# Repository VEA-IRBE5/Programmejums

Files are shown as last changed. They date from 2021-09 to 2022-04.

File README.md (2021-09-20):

# Programmējums
Zondes borta datora (mikrokontroliera) programmējums

# Programmēšanas stila vadlīnijas
Šīs ir tikai vadlīnijas, nesitīšu ja perfekti nesekosiet tām. Galvenais, lai kods ir saprotams un pārskatāms
- Tabulācija ir 4 atstarpes
- Komentārus var latviski/english, galvenais lai ir saprotami un labi apraksta kodu
- Iesaku komentārus netaupīt, tiklīdz kaut kas liekas ne pilnīgi pašsaprotams, raksti komentāru
- Komentāru garumam nevajadzētu pārsniegt 2 - 3 līnijas

## Mainīgo noformējums
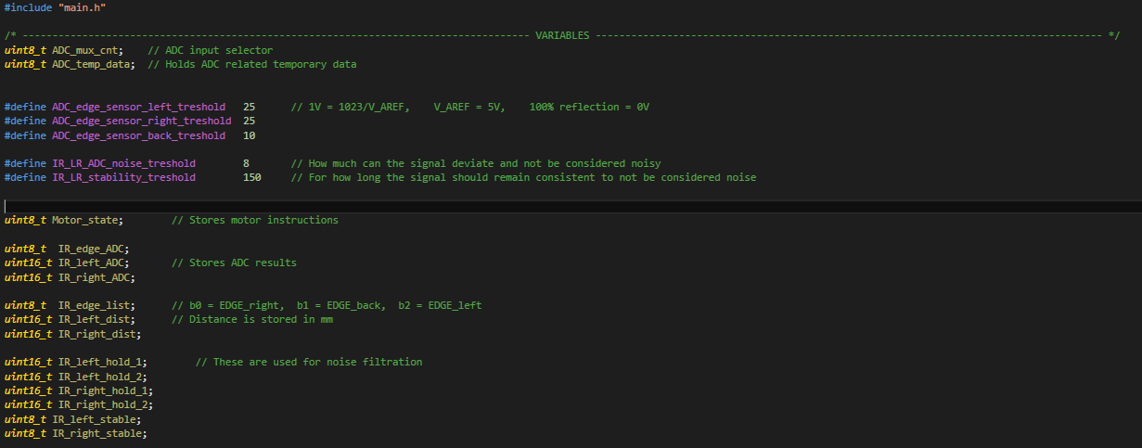
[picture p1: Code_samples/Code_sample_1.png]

- Mainīgo nosaukums var būt īsi līdz vidēji tekstuāls, galvenais lai no nosaukuma ir aptuveni skaidrs, kur izmanto
- Visim mainīgiem ir jābūt definētiem vienā vietā (vai divās) un, kur nepieiciešams, ar komentāriem aprakstīts to pielietojums
- Šīs pašas vadlīnijas arī attiecas uz definētām konstantēm
- Lūgums turēt mainīgos ārpus header (main.h) faila, cik iespējams (Uz konstantēm tas neattiecas)

## Koda noformējums
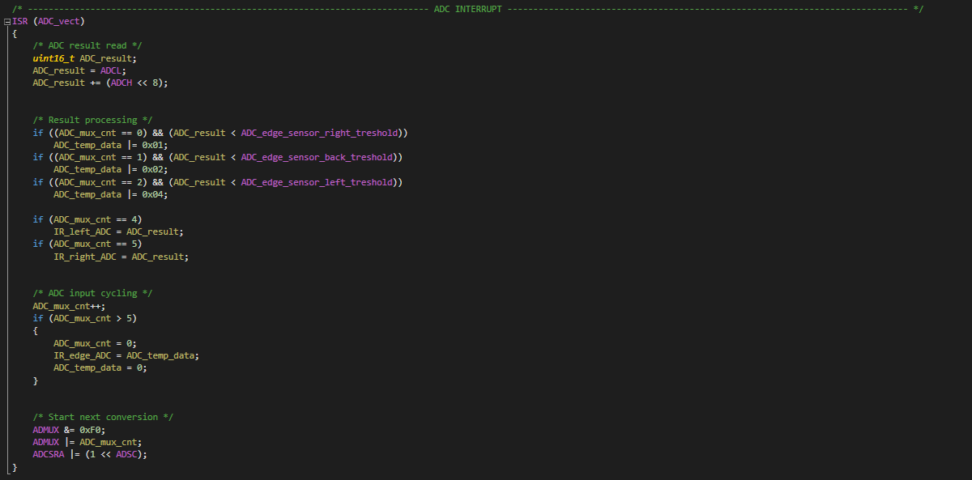
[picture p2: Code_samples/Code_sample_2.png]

- Galvenā doma ir sadalīšana pa blokiem ar attiecīgām komentētām sadalēm
- Piemērā ir redzams ADC pārtraukums kā galvenais bloks, ar iekšējiem darbības soļiem sadalītiem mazākos blokos
- Var dalīt kodu pa blokiem arī pēc saviem ieskatiem, galvenais lai ir labi sadalīts

## #include un funkcijas
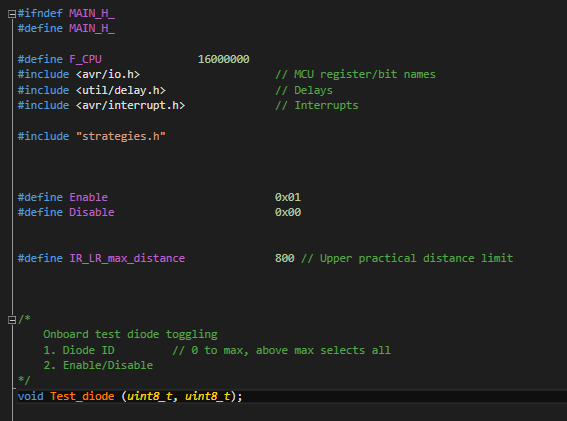
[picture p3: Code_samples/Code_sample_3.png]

- Pie #include droši rakstiet komentārus
- Funkcijām lūdzu veidot aprakstu, pasakot ko dara, ko ievada (ar mainīgo aprakstu) un ko izvada
- Ja izmantojat gatavus koda blokus no citiem avotiem, tos iesaku turēt atsevišķos failos un integrēt kā funkcijas

# Git bash konfigurācija un lokālās repozitorijas izveide

### 1. Instalē git bash

### 2. Izveido mapi, kurā glabās projektu

### 3. R-click(otrais peles taustiņš) -> Git bash here
  - Ja nerāda, atver git bash un ar cd navigē uz izveidoto mapi

### 4. Konsolē: git config --global user.name "Vards Uzvards" 
- git config --global user.email "epasts@mail.com"
  - Izmanto to epastu, kurš piesaistīts profilam, kas var tikt klāt IRBE5 repozitorijai
  - Var pārbaudīt, vai pareizi saglabāts ar tām pašām komandām, noņemot "" specificētos datus

### 5. (Neobligāts)Konsolē: git config --global core.editor "'C:/Program Files/Notepad++/notepad++.exe' -multiInst -notabbar -nosession -noPlugin"
  - var uzstādīt notepad++ kā default teksta editoru, kad raksta commit komentāru
  - Iesaku izdarīt, jo konsoles teksta editors nav ērts

### 6. Konsolē: git config --global init.defaultBranch main
- Citādi defaults būs master, un tas var radīt problēmas

### 7. Konsolē: git config --list
- Ar šo var pārbaudīt git bash konfigurāciju

### 8. Beidzot inicializē lokālo repozitoriju: git init

# Darbība ar lokālo github repositoriju

### 1. Konsolē: git remote add IRBE5 https://github.com/VEA-IRBE5/Programmejums.git
- turpmāk pie git pull var izmantot IRBE5 nevis pilno linku 
- ar šo pastās, vai sarakstā ir Konsolē: git remote -v

### 2. Konsolē: git pull IRBE5 [Branch name]
- Lejupielādē norādītā zara saturu no repozitorijas, par zaru lietošanu konsultējies ar nodaļas galveno

### 3. Pēc pašreizējās darba tūres beigšanas neaizmirsti izveidot commit, lai dati nepazūd
- Konsolē: git add . (vai git add "filename", ja negrib visas izmaiņas pievienot)
- Konsolē: git status (pastās, vai viss ir ok)
- Konsolē: git commit (Lūdzu izsmeļoši un ne pārāk gari aprakstiet izmainīto)(var izmantot: -m "Text here")
   
### 4. Kad liekas, ka pašreizējais uzdevums ir gana labā stāvoklī, Konsolē: git push IRBE5 [Branch name]

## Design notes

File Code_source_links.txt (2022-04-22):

http://www.emcu.eu/how-to-manage-two-uart-usart2-and-usart1-under-interrupt/
https://github.com/Xxxxhx/STM32_HAL_Tutorial/blob/master/4-Timer%20Interrupt.md
https://the78mole.de/stm32-uart-continuous-receive-with-interrupt/
https://controllerstech.com/sd-card-using-spi-in-stm32/
https://cdn-shop.adafruit.com/datasheets/Si1145-46-47.pdf

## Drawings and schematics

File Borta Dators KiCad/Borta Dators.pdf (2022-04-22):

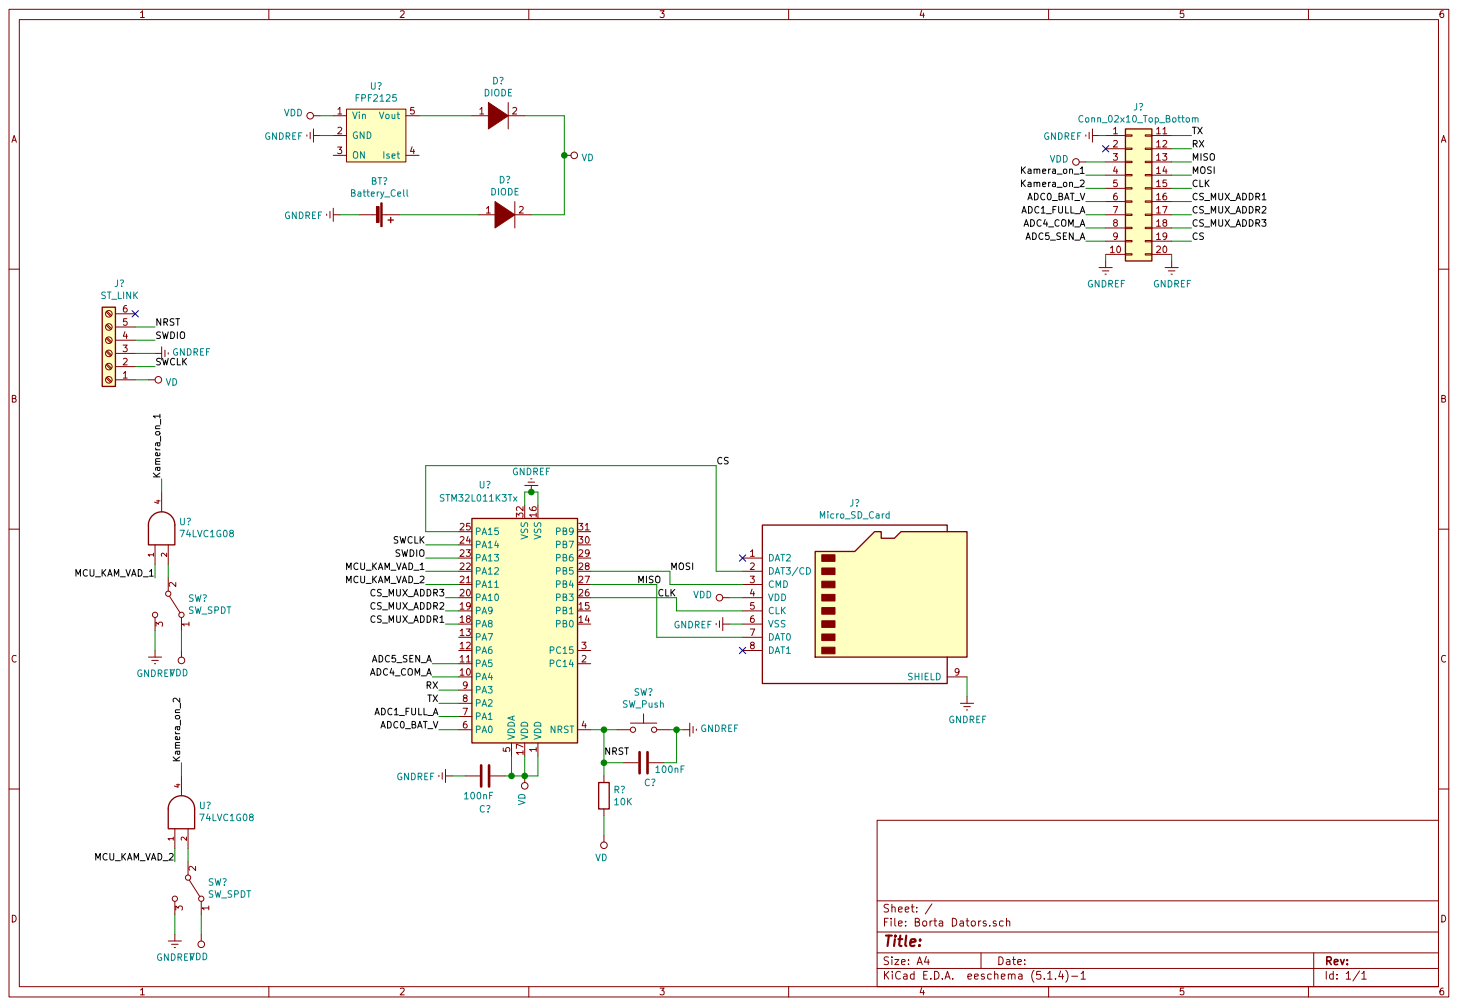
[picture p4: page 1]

Id: 1/1 Title: File: Borta Dators.sch Sheet: /

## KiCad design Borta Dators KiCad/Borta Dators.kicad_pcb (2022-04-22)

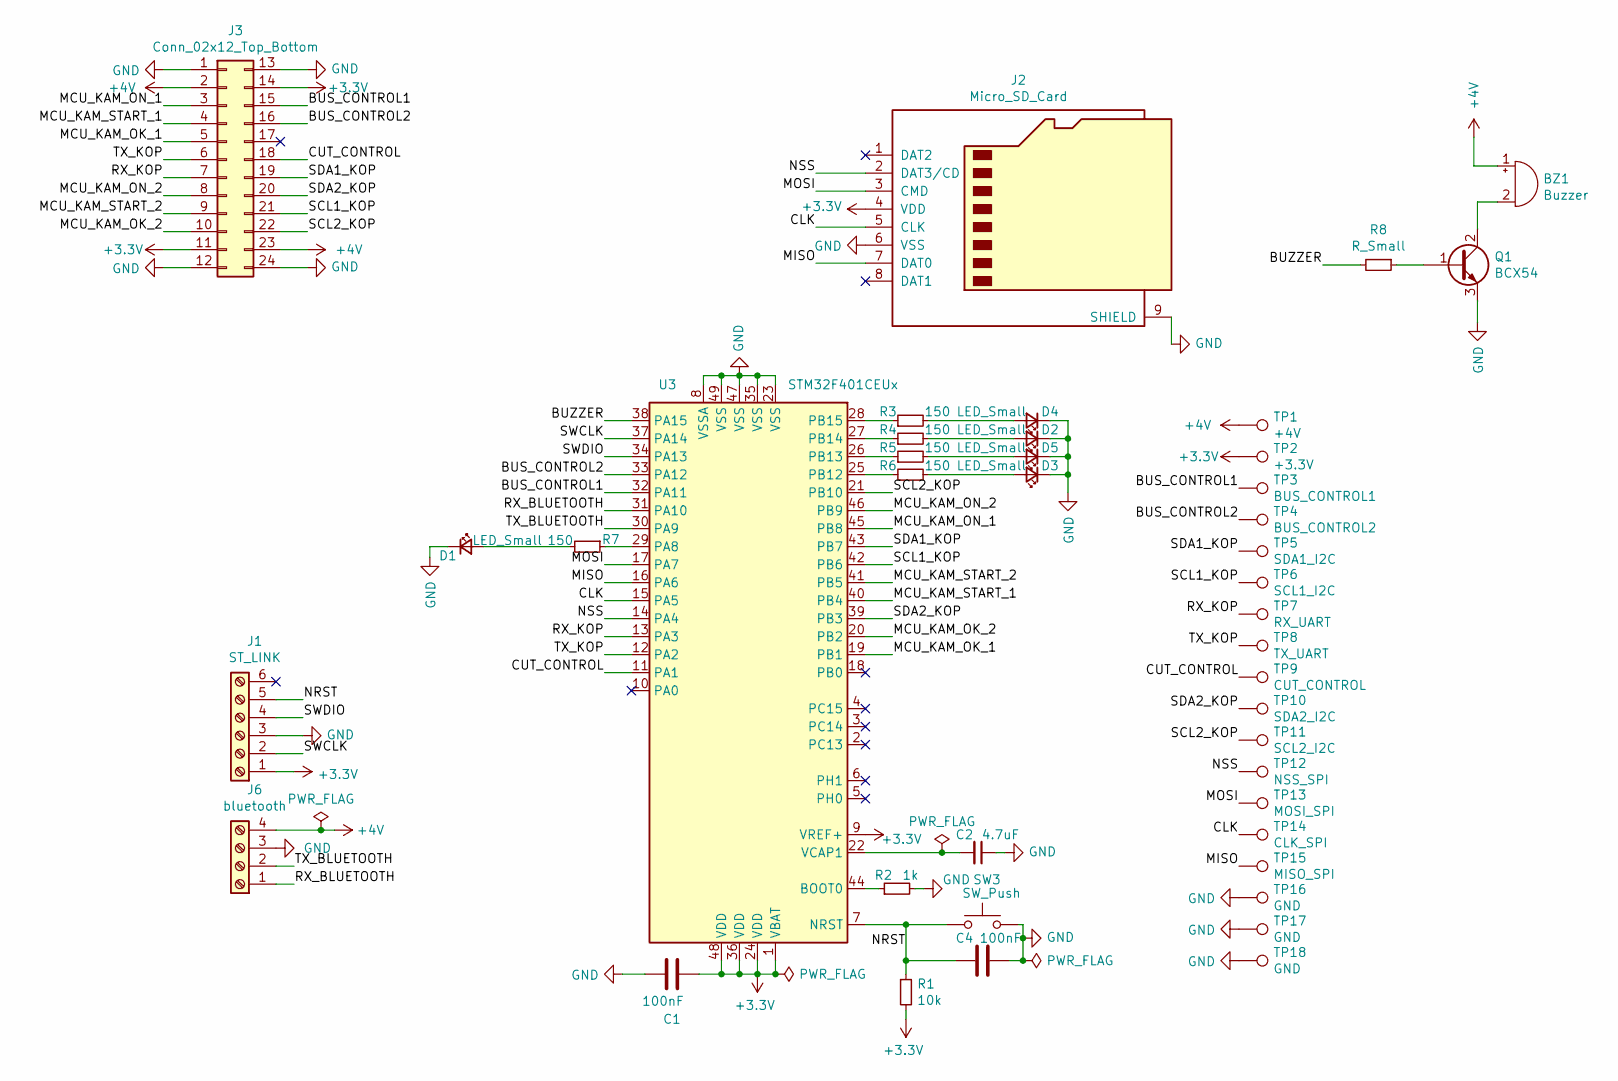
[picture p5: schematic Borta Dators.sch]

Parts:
BZ1: Buzzer; PinHeader_1x02_P1.27mm_Vertical
C1, C4: 100nF; C_0603_1608Metric_Pad1.08x0.95mm_HandSolder
C2: 4.7uF; C_0603_1608Metric_Pad1.08x0.95mm_HandSolder
D1, D2, D3, D4, D5: LED_Small; D_0603_1608Metric_Pad1.05x0.95mm_HandSolder
J1: ST_LINK; PinSocket_1x06_P2.54mm_Vertical
J2: Micro_SD_Card; Micro_SD
J3: Conn_02x12_Top_Bottom; SAMTEC-SSW-112-02-X-D-RA
J6: bluetooth; PinSocket_1x04_P2.54mm_Vertical
Q1: BCX54; SOT-89-3
R1: 10k; R_0603_1608Metric_Pad0.98x0.95mm_HandSolder
R2: 1k; R_0603_1608Metric_Pad0.98x0.95mm_HandSolder
R3, R4, R5, R6, R7: 150; R_0603_1608Metric_Pad0.98x0.95mm_HandSolder
R8: R_Small; R_0603_1608Metric_Pad0.98x0.95mm_HandSolder
SW3: SW_Push; SW_SPST_EVQQ2
TP1: +4V; PinHeader_1x01_P2.54mm_Vertical
TP2: +3.3V; PinHeader_1x01_P2.54mm_Vertical
TP3: BUS_CONTROL1; PinHeader_1x01_P2.54mm_Vertical
TP4: BUS_CONTROL2; PinHeader_1x01_P2.54mm_Vertical
TP5: SDA1_I2C; PinHeader_1x01_P2.54mm_Vertical
TP6: SCL1_I2C; PinHeader_1x01_P2.54mm_Vertical
TP7: RX_UART; PinHeader_1x01_P2.54mm_Vertical
TP8: TX_UART; PinHeader_1x01_P2.54mm_Vertical
TP9: CUT_CONTROL; PinHeader_1x01_P2.54mm_Vertical
TP10: SDA2_I2C; PinHeader_1x01_P2.54mm_Vertical
TP11: SCL2_I2C; PinHeader_1x01_P2.54mm_Vertical
TP12: NSS_SPI; PinHeader_1x01_P2.54mm_Vertical
TP13: MOSI_SPI; PinHeader_1x01_P2.54mm_Vertical
TP14: CLK_SPI; PinHeader_1x01_P2.54mm_Vertical
TP15: MISO_SPI; PinHeader_1x01_P2.54mm_Vertical
TP16, TP17, TP18: GND; PinHeader_1x01_P2.54mm_Vertical
U3: STM32F401CEUx; QFN-48-1EP_7x7mm_P0.5mm_EP5.6x5.6mm

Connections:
+3V3: C1.1, J1.1, J2.4 (VDD), J3.11, J3.14, R1.2, TP2.1, U3.1 (VBAT), U3.9 (VREF+), U3.24 (VDD), U3.36 (VDD), U3.48 (VDD); also elsewhere on the board
+4V: BZ1.1 (-), J3.2, J3.23, J6.4, TP1.1
/BUS_CONTROL1: J3.15, TP3.1, U3.32 (PA11); also elsewhere on the board
/BUS_CONTROL2: J3.16, TP4.1, U3.33 (PA12); also elsewhere on the board
/BUZZER: R8.2, U3.38 (PA15); also elsewhere on the board
/CLK: J2.5 (CLK), TP14.1, U3.15 (PA5); also elsewhere on the board
/CUT_CONTROL: J3.18, TP9.1, U3.11 (PA1); also elsewhere on the board
/MCU_KAM_OK_1: J3.5, U3.19 (PB1); also elsewhere on the board
/MCU_KAM_OK_2: J3.10, U3.20 (PB2); also elsewhere on the board
/MCU_KAM_ON_1: J3.3, U3.45 (PB8); also elsewhere on the board
/MCU_KAM_ON_2: J3.8, U3.46 (PB9); also elsewhere on the board
/MCU_KAM_START_1: J3.4, U3.40 (PB4); also elsewhere on the board
/MCU_KAM_START_2: J3.9, U3.41 (PB5); also elsewhere on the board
/MISO: J2.7 (DAT0), TP15.1, U3.16 (PA6); also elsewhere on the board
/MOSI: J2.3 (CMD), TP13.1, U3.17 (PA7); also elsewhere on the board
/NRST: C4.1, J1.5, R1.1, SW3.1, U3.7 (NRST); also elsewhere on the board
/NSS: J2.2 (DAT3/CD), TP12.1, U3.14 (PA4); also elsewhere on the board
/RX_BLUETOOTH: J6.1, U3.31 (PA10); also elsewhere on the board
/RX_KOP: J3.7, TP7.1, U3.13 (PA3); also elsewhere on the board
/SCL1_KOP: J3.21, TP6.1, U3.42 (PB6); also elsewhere on the board
/SCL2_KOP: J3.22, TP11.1, U3.21 (PB10); also elsewhere on the board
/SDA1_KOP: J3.19, TP5.1, U3.43 (PB7); also elsewhere on the board
/SDA2_KOP: J3.20, TP10.1, U3.39 (PB3); also elsewhere on the board
/SWCLK: J1.2, U3.37 (PA14); also elsewhere on the board
/SWDIO: J1.4, U3.34 (PA13); also elsewhere on the board
/TX_BLUETOOTH: J6.2, U3.30 (PA9); also elsewhere on the board
/TX_KOP: J3.6, TP8.1, U3.12 (PA2); also elsewhere on the board
GND: C1.2, C2.1, C4.2, D1.1 (K), D2.1 (K), D3.1 (K), D4.1 (K), D5.1 (K), J1.3, J2.6 (VSS), J2.9 (SHIELD), J3.1, J3.12, J3.13, J3.24, J6.3, Q1.3 (E), R2.2, SW3.2, TP16.1, TP17.1, TP18.1, U3.8 (VSSA), U3.23 (VSS), U3.35 (VSS), U3.47 (VSS), U3.49 (VSS); also elsewhere on the board
unnamed: BZ1.2 (+), Q1.2 (C)
unnamed 29: C2.2, U3.22 (VCAP1); also elsewhere on the board
unnamed: D1.2 (A), R7.2
unnamed: D2.2 (A), R4.2
unnamed: D3.2 (A), R6.2
unnamed: D4.2 (A), R3.2
unnamed: D5.2 (A), R5.2
unnamed: Q1.1 (B), R8.1
unnamed 40: R2.1, U3.44 (BOOT0); also elsewhere on the board
unnamed 41: R3.1, U3.28 (PB15); also elsewhere on the board
unnamed 42: R4.1, U3.27 (PB14); also elsewhere on the board
unnamed 43: R5.1, U3.26 (PB13); also elsewhere on the board
unnamed 44: R6.1, U3.25 (PB12); also elsewhere on the board
unnamed 45: R7.1, U3.29 (PA8); also elsewhere on the board

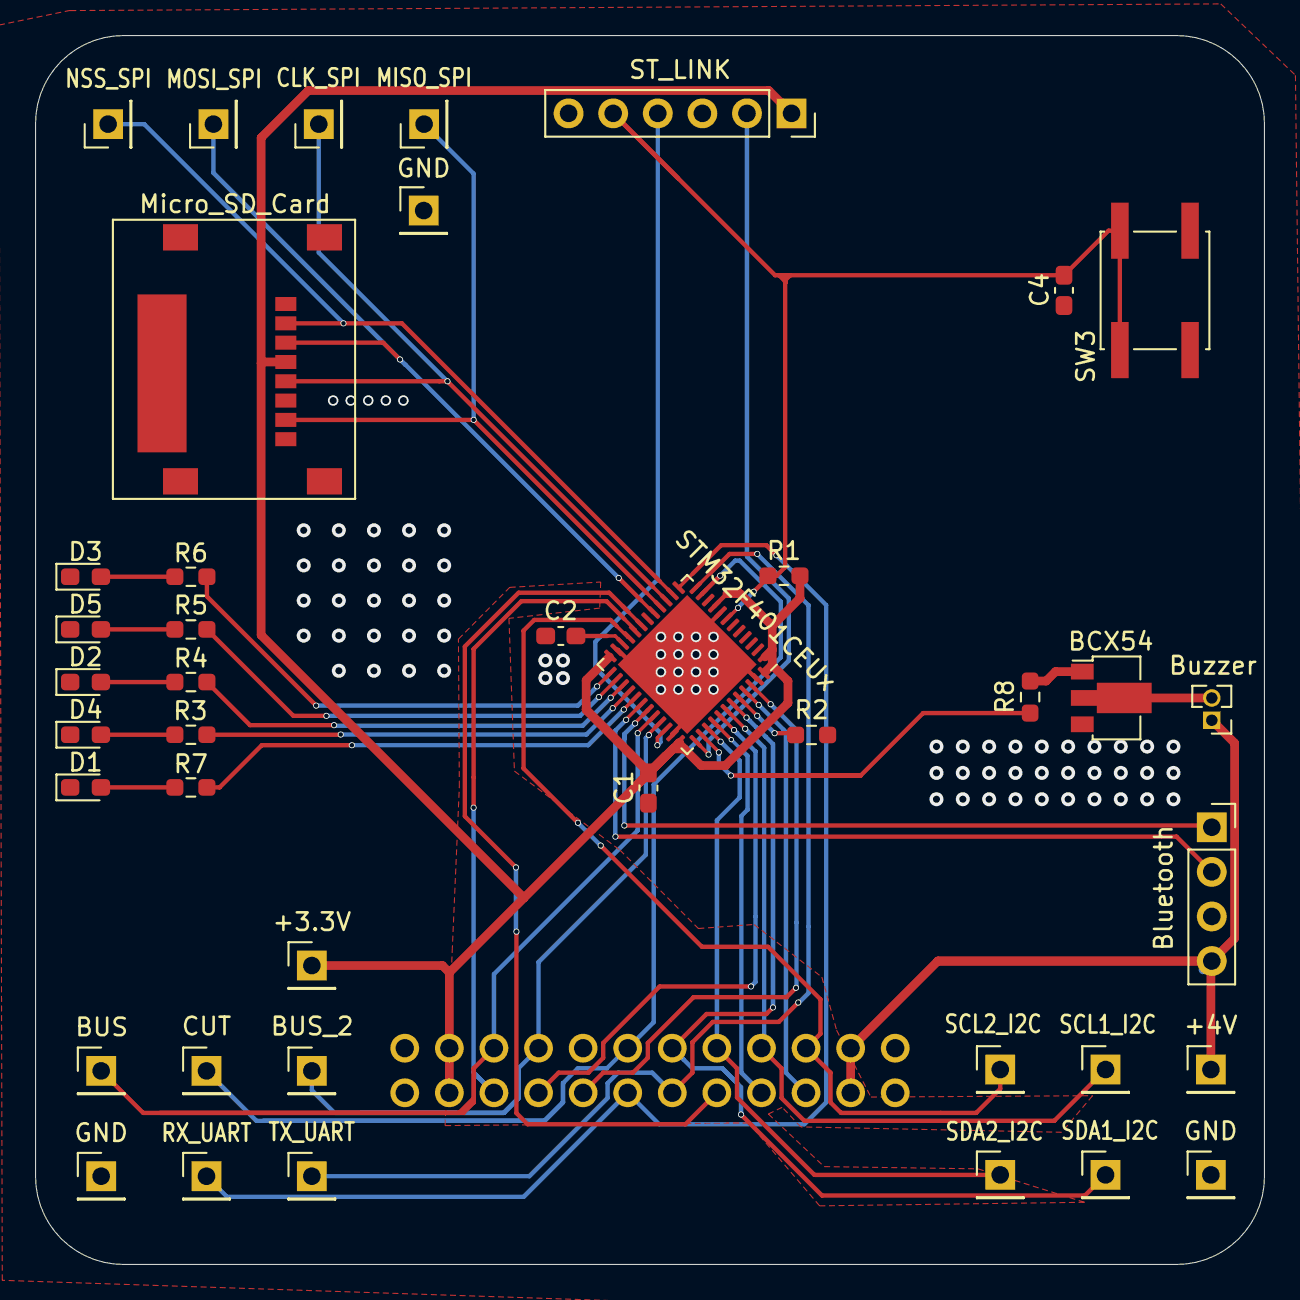
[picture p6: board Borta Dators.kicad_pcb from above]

Board: 2 copper layers, 70.0 x 70.0 mm, 42 parts (0 on the bottom side), 42 nets.

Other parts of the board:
TP109: BUS_2; PinHeader_1x01_P2.54mm_Vertical
Ue: STM32F401CEUx; QFN-48-1EP_7x7mm_P0.5mm_EP5.6x5.6mm

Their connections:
+3V3: Ue.1, Ue.9, Ue.24, Ue.36, Ue.48; also elsewhere on the board
/BUS_CONTROL1: Ue.32; also elsewhere on the board
/BUS_CONTROL2: TP109.1, Ue.33; also elsewhere on the board
/BUZZER: Ue.38; also elsewhere on the board
/CLK: Ue.15; also elsewhere on the board
/CUT_CONTROL: Ue.11; also elsewhere on the board
/MCU_KAM_OK_1: Ue.19; also elsewhere on the board
/MCU_KAM_OK_2: Ue.20; also elsewhere on the board
/MCU_KAM_ON_1: Ue.45; also elsewhere on the board
/MCU_KAM_ON_2: Ue.46; also elsewhere on the board
/MCU_KAM_START_1: Ue.40; also elsewhere on the board
/MCU_KAM_START_2: Ue.41; also elsewhere on the board
/MISO: Ue.16; also elsewhere on the board
/MOSI: Ue.17; also elsewhere on the board
/NRST: Ue.7; also elsewhere on the board
/NSS: Ue.14; also elsewhere on the board
/RX_BLUETOOTH: Ue.31; also elsewhere on the board
/RX_KOP: Ue.13; also elsewhere on the board
/SCL1_KOP: Ue.42; also elsewhere on the board
/SCL2_KOP: Ue.21; also elsewhere on the board
/SDA1_KOP: Ue.43; also elsewhere on the board
/SDA2_KOP: Ue.39; also elsewhere on the board
/SWCLK: Ue.37; also elsewhere on the board
/SWDIO: Ue.34; also elsewhere on the board
/TX_BLUETOOTH: Ue.30; also elsewhere on the board
/TX_KOP: Ue.12; also elsewhere on the board
GND: Ue.8, Ue.23, Ue.35, Ue.47, Ue.49; also elsewhere on the board
unnamed 29: Ue.22; also elsewhere on the board
unnamed 40: Ue.44; also elsewhere on the board
unnamed 41: Ue.28; also elsewhere on the board
unnamed 42: Ue.27; also elsewhere on the board
unnamed 43: Ue.26; also elsewhere on the board
unnamed 44: Ue.25; also elsewhere on the board
unnamed 45: Ue.29; also elsewhere on the board

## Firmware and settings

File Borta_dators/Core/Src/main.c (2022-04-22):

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
/* Includes ------------------------------------------------------------------*/
#include "main.h"
#include "fatfs.h"

/* USER CODE BEGIN Includes */
#include <math.h>
#include <stdio.h>
#include <string.h>
#include "BME280_lib.h"
#include "MPU6050_Lib.h"
#include "SI1145_lib.h"
/* USER CODE END Includes */

/* USER CODE BEGIN PD */

/* Buffer sizes */
#define UART_Buffer_size 50		// 2B command or nB data


/* Rope cut and sleep mode defines */
#define ROPE_NOT_CUT 0
#define ROPE_CUTTING 1
#define ROPE_CUT_DONE 2

#define ROPE_CUT_TIME 10			// in seconds
#define LOWER_ALTITUDE_LIMIT 1000 	// in meters
#define UPPER_ALTITUDE_LIMIT 28000 	// in meters
#define ALTITUDE_UPDATE_PERIOD 30	// in seconds


/* Sensor related defines */
#define I2C_BUS_SEL_BMEs 0
#define I2C_BUS_SEL_MPU__SI 1
#define I2C_handle_BME_ex__SI hi2c1
#define I2C_handle_BME_in__MPU hi2c2
#define I2C_short_timeout 20
#define I2C_long_timeout 200
#define PRESSURE_REFERENCE 100	//kpa at sea level, varies by location and weather


/* SD card related defines */
#define SD_MAX_RETRIES 5


/* Camera related defines */
#define CAM_NOK 0
#define CAM_OK 1
#define CAM_NREC 0
#define CAM_REC 1
#define CAM_STARTUP_TIME 6	// x*5 seconds

///* Timeout error defines */
//#define Timeout_none 0
//#define Timeout_SDcard 1
//#define Timeout_COM_uart 2
//#define Timeout_sensors 3

/* USER CODE END PD */

/* USER CODE BEGIN PM */
#define ARRAY_LENGTH(x) sizeof(x)/sizeof(x[0])

///* Timeout macros */
//#define Set_Timeout_Delay_ms(ms) __HAL_TIM_SET_AUTORELOAD(&htim2, ms)
//#define Start_Timeout __HAL_TIM_SET_COUNTER(&htim2, 0); HAL_TIM_Base_Start_IT(&htim2)
//#define Stop_Timeout HAL_TIM_Base_Stop_IT(&htim2)

/* USER CODE END PM */

I2C_HandleTypeDef hi2c1;
I2C_HandleTypeDef hi2c2;

RTC_HandleTypeDef hrtc;

SPI_HandleTypeDef hspi1;

TIM_HandleTypeDef htim3;
TIM_HandleTypeDef htim4;
TIM_HandleTypeDef htim5;
TIM_HandleTypeDef htim9;
TIM_HandleTypeDef htim10;

UART_HandleTypeDef huart1;
UART_HandleTypeDef huart2;

/* USER CODE BEGIN PV */

/* SD card handling variables */
FATFS fs;
FATFS *pfs;
FIL fil;
FRESULT fres;
DWORD fre_clust;
volatile uint32_t totalSpace, freeSpace;
char buffer[100];
volatile FRESULT sd_status;
volatile uint8_t sd_mounted;
volatile uint8_t sd_file_cnt;
volatile uint8_t sd_error_cnt;


/* System core and misc variables */
volatile uint8_t Is_asleep;
volatile uint8_t Rope_cut_delay, Rope_cut_status;
char message[] = "--test-please-ignore--";


/* Sensor data storage variables */
Sensors_struct Sensors;
char Data_to_send[UART_Buffer_size];

volatile uint16_t Cycle_runtime_last;
volatile uint16_t Cycle_runtime_min;
volatile uint16_t Cycle_runtime_max;

RTC_TimeTypeDef Current_Time;
RTC_DateTypeDef Current_Date;
volatile double Altitude_max;



/* UART1 specific */
uint8_t UART1_TxBuf[UART_Buffer_size];
uint8_t UART1_RxBuf[UART_Buffer_size];
uint8_t UART1_DataBuf[UART_Buffer_size];
volatile uint8_t UART1_RxIsData;
volatile uint8_t UART1_RxBytes;


/* UART2 specific */
uint8_t UART2_TxBuf[UART_Buffer_size];
uint8_t UART2_RxBuf[UART_Buffer_size];
uint8_t UART2_DataBuf[UART_Buffer_size];
volatile uint8_t UART2_RxIsData;
volatile uint8_t UART2_RxBytes;


/* CAM specific */
typedef struct CAM_struct
{
	GPIO_TypeDef *ON_PORT;
	uint16_t ON_PIN;
	GPIO_TypeDef *OK_PORT;
	uint16_t OK_PIN;
	GPIO_TypeDef *START_PORT;
	uint16_t START_PIN;
	TIM_HandleTypeDef *TIM;
	uint8_t REC_STATUS;
	uint8_t Do_Restart;
	uint8_t Do_EXTI;
	uint8_t Startup_delay;
} CAM_struct;

CAM_struct CAM_1;
CAM_struct CAM_2;

/* USER CODE END PV */

void SystemClock_Config(void);
static void MX_GPIO_Init(void);
static void MX_USART2_UART_Init(void);
static void MX_TIM4_Init(void);
static void MX_USART1_UART_Init(void);
static void MX_SPI1_Init(void);
static void MX_RTC_Init(void);
static void MX_TIM3_Init(void);
static void MX_I2C1_Init(void);
static void MX_I2C2_Init(void);
static void MX_TIM5_Init(void);
static void MX_TIM9_Init(void);
static void MX_TIM10_Init(void);
/* USER CODE BEGIN PFP */

void I2C_Select_bus(uint8_t select);
uint8_t Get_System_Status();
void Get_BME280_in_all_readings();
void Get_BME280_ex_all_readings();
void Get_MPU6050_all_readings();
void Get_SI1145_all_readings();
uint8_t Mount_open_SD_Card();

/* USER CODE END PFP */

/* USER CODE BEGIN 0 */


uint8_t Get_System_Status()
{
	uint8_t status = 0;

	if(Is_asleep == 1)
		status |= 1 << 8;
	if(Sensors.BME280_Internal.Status == HAL_OK)
		status |= 1 << 6;
	if(Sensors.BME280_External.Status == HAL_OK)
		status |= 1 << 5;
	if(Sensors.MPU650.Status == HAL_OK)
		status |= 1 << 4;
	if(Sensors.SI1145.Status == HAL_OK)
		status |= 1 << 3;
	if(sd_status == FR_OK)
		status |= 1 << 2;
	if(CAM_1.REC_STATUS == CAM_REC)
		status |= 1 << 1;
	if(CAM_2.REC_STATUS == CAM_REC)
		status |= 1;

	return status;
}
/*
 * Use defined I2C_BUS_SEL_ for input
 * anything not defined (above 1) deselects both
 */
void I2C_Select_bus(uint8_t select)
{
	switch(select)
	{
	case I2C_BUS_SEL_BMEs:
		HAL_GPIO_WritePin(BUS_SEL_1_GPIO_Port, BUS_SEL_1_Pin, GPIO_PIN_SET);
		HAL_GPIO_WritePin(BUS_SEL_2_GPIO_Port, BUS_SEL_2_Pin, GPIO_PIN_RESET);
		break;

	case I2C_BUS_SEL_MPU__SI:
		HAL_GPIO_WritePin(BUS_SEL_2_GPIO_Port, BUS_SEL_2_Pin, GPIO_PIN_SET);
		HAL_GPIO_WritePin(BUS_SEL_1_GPIO_Port, BUS_SEL_1_Pin, GPIO_PIN_RESET);
		break;

	default:
		HAL_GPIO_WritePin(BUS_SEL_1_GPIO_Port, BUS_SEL_1_Pin, GPIO_PIN_SET);
		HAL_GPIO_WritePin(BUS_SEL_2_GPIO_Port, BUS_SEL_2_Pin, GPIO_PIN_SET);
		break;
	}
}


void Get_BME280_in_all_readings()
{
	I2C_Select_bus(I2C_BUS_SEL_BMEs);
	Sensors.BME280_Internal.Status = BME280_Get_ID(I2C_handle_BME_in__MPU, &Sensors.BME280_Internal.ID, I2C_short_timeout);
	if(Sensors.BME280_Internal.Status != HAL_OK)
		return;
	Sensors.BME280_Internal.Status = BME280_Get_All(I2C_handle_BME_in__MPU, I2C_long_timeout);
	if(Sensors.BME280_Internal.Status != HAL_OK)
		return;

	Sensors.BME280_Internal.Temperature = BME280_T_Double(&BME280_internal_Calib_Data);
	Sensors.BME280_Internal.Pressure = BME280_P_Double(&BME280_internal_Calib_Data);
	Sensors.BME280_Internal.Humidity = BME280_H_Double(&BME280_internal_Calib_Data);
	Sensors.BME280_Internal.Altitude = BME280_Altitude_Double(Sensors.BME280_Internal.Pressure, Sensors.BME280_Internal.Pressure_ref);
}


void Get_BME280_ex_all_readings()
{
	I2C_Select_bus(I2C_BUS_SEL_BMEs);
	Sensors.BME280_External.Status = BME280_Get_ID(I2C_handle_BME_ex__SI, &Sensors.BME280_External.ID, I2C_short_timeout);
	if(Sensors.BME280_External.Status != HAL_OK)
		return;
	Sensors.BME280_External.Status = BME280_Get_All(I2C_handle_BME_ex__SI, I2C_long_timeout);
	if(Sensors.BME280_External.Status != HAL_OK)
		return;

	Sensors.BME280_External.Temperature = BME280_T_Double(&BME280_external_Calib_Data);
	Sensors.BME280_External.Pressure = BME280_P_Double(&BME280_external_Calib_Data);
	Sensors.BME280_External.Humidity = BME280_H_Double(&BME280_external_Calib_Data);
	Sensors.BME280_External.Altitude = BME280_Altitude_Double(Sensors.BME280_External.Pressure, Sensors.BME280_External.Pressure_ref);
}


void Get_MPU6050_all_readings()
{
	I2C_Select_bus(I2C_BUS_SEL_MPU__SI);
	Sensors.MPU650.Status = MPU6050_read_ID(I2C_handle_BME_in__MPU, &Sensors.MPU650.ID, I2C_short_timeout);
	if(Sensors.MPU650.Status != HAL_OK)
		return;
	Sensors.MPU650.Status = MPU6050_read_All(I2C_handle_BME_in__MPU, I2C_long_timeout);
	if(Sensors.MPU650.Status != HAL_OK)
		return;

	MPU6050_Accel_double(&Sensors.MPU650);
	MPU6050_Gyro_double(&Sensors.MPU650);
	MPU6050_Temp_double(&Sensors.MPU650);
}


void Get_SI1145_all_readings()
{
	I2C_Select_bus(I2C_BUS_SEL_MPU__SI);
	Sensors.SI1145.Status = SI1145_read_ID(I2C_handle_BME_ex__SI, &Sensors.SI1145.ID, I2C_short_timeout);
	if(Sensors.SI1145.Status != HAL_OK)
		return;
	Sensors.SI1145.Status = SI1145_Read_Data(I2C_handle_BME_ex__SI, I2C_long_timeout);
	if(Sensors.SI1145.Status != HAL_OK)
		return;

	Sensors.SI1145.VIS = SI1145_VIS_raw();
	Sensors.SI1145.IR = SI1145_IR_raw();
	Sensors.SI1145.UV = SI1145_UV_double();
}


/* Returns FR_status after success or last failed step */
uint8_t Mount_open_SD_Card()
{
	uint8_t sd_mounting_status;

	/* Mount SD Card */
	sd_mounting_status = f_mount(&fs, "", 1);
	if(sd_mounting_status != FR_OK)
		return sd_mounting_status;

	/* Open file to write */
	sd_mounting_status = f_open(&fil, "Data0.txt", FA_OPEN_ALWAYS | FA_WRITE);
	if(sd_mounting_status != FR_OK)
		return sd_mounting_status;

	/* Check freeSpace space */
	sd_mounting_status = f_getfree("", &fre_clust, &pfs);
	if(sd_mounting_status != FR_OK)
		return sd_mounting_status;
	totalSpace = (uint32_t)((pfs->n_fatent - 2) * pfs->csize * 0.5);
	freeSpace = (uint32_t)(fre_clust * pfs->csize * 0.5);

	/* free space is less than 1kb */
	if(freeSpace < 1)
	{
		sd_mounting_status = 0xDF;
		return sd_mounting_status;
	}

	/* Writing header text */
	f_printf(&fil, "STM32 SD Card data logger\n");
	f_printf(&fil, "RTC time and sensor readings (SI VIS and SI IR are raw values)\n");
	f_printf(&fil, "SD-CARD-MEMORY = %d \n SD-CARD-FREE-MEMORY = %d\n", totalSpace, freeSpace);
	f_printf(&fil, "| Dt | Hr | Mn | Sc |");
	f_printf(&fil, " BME_in T | BME_in P | BME_in H | BME_in A |");
	f_printf(&fil, " BME_ex T | BME_ex P | BME_ex H | BME_in A |");
	f_printf(&fil, " MPU Acc_X | MPU Acc_Y | MPU Acc_Z | MPU Gyr_X | MPU Gyr_Y | MPU Gyr_Z | MPU Tmpr  |");
	f_printf(&fil, " SI VIS | SI IR  | SI UV  |\n");
	sd_mounting_status = f_sync(&fil);
	return sd_mounting_status;
}


void CAM_ON(CAM_struct *CAM)
{
	// Checks if CAM is OFF
	if(HAL_GPIO_ReadPin(CAM->OK_PORT, CAM->OK_PIN) == 0)
	{
		HAL_GPIO_WritePin(CAM->ON_PORT, CAM->ON_PIN, GPIO_PIN_SET);
		HAL_Delay(100);
		HAL_GPIO_WritePin(CAM->ON_PORT, CAM->ON_PIN, GPIO_PIN_RESET);
		CAM->Startup_delay = CAM_STARTUP_TIME;
	}
	// Start heartbeat monitoring
	CAM->Do_EXTI = 1;
}


void CAM_START(CAM_struct *CAM)
{
	// Checks if CAM is ON and not recording
	if((CAM->REC_STATUS == CAM_NREC) && (HAL_GPIO_ReadPin(CAM->OK_PORT, CAM->OK_PIN) == 1) && (CAM->Startup_delay == 0))
	{
		HAL_GPIO_WritePin(CAM->OK_PORT, CAM->OK_PIN, GPIO_PIN_RESET);
		HAL_Delay(30);
		HAL_GPIO_WritePin(CAM->OK_PORT, CAM->OK_PIN, GPIO_PIN_SET);
	}

	if(HAL_GPIO_ReadPin(CAM->OK_PORT, CAM->OK_PIN) == 0)
		CAM_ON(CAM);

	// Start filming restart routine
	CAM->Do_Restart = 1;
}


void CAM_STOP(CAM_struct *CAM)
{
	// Checks if CAM is recording
	if(CAM->REC_STATUS == CAM_REC)
	{
		HAL_GPIO_WritePin(CAM->OK_PORT, CAM->OK_PIN, GPIO_PIN_RESET);
		HAL_Delay(30);
		HAL_GPIO_WritePin(CAM->OK_PORT, CAM->OK_PIN, GPIO_PIN_SET);
		CAM->REC_STATUS = CAM_NREC;
	}

	// Stop filming restart routine
	CAM->Do_Restart = 0;
}


void CAM_OFF(CAM_struct *CAM)
{
	// checks if CAM is ON
	if(HAL_GPIO_ReadPin(CAM->OK_PORT, CAM->OK_PIN))
	{
		HAL_GPIO_WritePin(CAM->ON_PORT, CAM->ON_PIN, GPIO_PIN_RESET);
		HAL_Delay(100);
		HAL_GPIO_WritePin(CAM->ON_PORT, CAM->ON_PIN, GPIO_PIN_SET);
	}
	// Stop heartbeat monitoring
	CAM->Do_EXTI = 0;
}
/* USER CODE END 0 */

/**
  * @brief  The application entry point.
  * @retval int
  */
int main(void)
{
  /* MCU Configuration--------------------------------------------------------*/

  /* Reset of all peripherals, Initializes the Flash interface and the Systick. */
  HAL_Init();

  /* Configure the system clock */
  SystemClock_Config();

  /* Initialize all configured peripherals */
  MX_GPIO_Init();
  MX_USART2_UART_Init();
  MX_TIM4_Init();
  MX_USART1_UART_Init();
  MX_SPI1_Init();
  MX_RTC_Init();
  MX_FATFS_Init();
  MX_TIM3_Init();
  MX_I2C1_Init();
  MX_I2C2_Init();
  MX_TIM5_Init();
  MX_TIM9_Init();
  MX_TIM10_Init();
  /* USER CODE BEGIN 2 */


  /*---------------Core systems setup--------------------*/
	Is_asleep = 0;
	Rope_cut_status = ROPE_NOT_CUT;
	Rope_cut_delay = ROPE_CUT_TIME;
	Cycle_runtime_last = 0;
	Cycle_runtime_min = 0xFFFF;
	Cycle_runtime_max = 0;

	// Get RTC time (date must be read as well for proper updating or something)
	HAL_RTC_GetTime(&hrtc, &Current_Time, RTC_FORMAT_BIN);
	HAL_RTC_GetDate(&hrtc, &Current_Date, RTC_FORMAT_BIN);


  /*------------------SD card setup----------------------*/
	/* Wait for SD module reset */
	HAL_Delay(2000);

	sd_file_cnt = 0;
	sd_error_cnt = 0;
	sd_mounted = 0;
	sd_status = Mount_open_SD_Card();

	while(sd_status == FR_NOT_READY)
		sd_status = Mount_open_SD_Card();

	if(sd_status == FR_OK)
		sd_mounted = 1;
	else
	{
		UART1_TxBuf[0] = 0xD0;
		UART1_TxBuf[1] = sd_status;
		HAL_UART_Transmit_IT(&huart1, UART1_TxBuf, 2);
	}


  /*------------------Sensors init-----------------------*/
	Sensors.BME280_Internal.Pressure_ref = PRESSURE_REFERENCE;
	Sensors.BME280_External.Pressure_ref = PRESSURE_REFERENCE;


	/* Wait for Sensor power-on */
	HAL_Delay(1000);

	I2C_Select_bus(I2C_BUS_SEL_BMEs);
	Sensors.BME280_Internal.Status = BME280_Get_ID(I2C_handle_BME_in__MPU, &Sensors.BME280_Internal.ID, I2C_short_timeout);
	if (Sensors.BME280_Internal.Status == HAL_OK)
	{
		Sensors.BME280_Internal.Status = BME280_Init(I2C_handle_BME_in__MPU, I2C_short_timeout);
		Sensors.BME280_Internal.Status = BME280_Calib_Read(I2C_handle_BME_in__MPU, &BME280_internal_Calib_Data, I2C_long_timeout);
		Get_BME280_in_all_readings();
	}


	I2C_Select_bus(I2C_BUS_SEL_BMEs);
	Sensors.BME280_External.Status = BME280_Get_ID(I2C_handle_BME_ex__SI, &Sensors.BME280_External.ID, I2C_short_timeout);
	if (Sensors.BME280_External.Status == HAL_OK)
	{
		Sensors.BME280_External.Status = BME280_Init(I2C_handle_BME_ex__SI, I2C_short_timeout);
		Sensors.BME280_External.Status = BME280_Calib_Read(I2C_handle_BME_ex__SI, &BME280_external_Calib_Data, I2C_long_timeout);
		Get_BME280_ex_all_readings();
	}


	I2C_Select_bus(I2C_BUS_SEL_MPU__SI);
	Sensors.MPU650.Status = MPU6050_read_ID(I2C_handle_BME_in__MPU, &Sensors.MPU650.ID, I2C_short_timeout);
	if (Sensors.MPU650.Status == HAL_OK)
	{
		Sensors.MPU650.Status = MPU6050_Init(I2C_handle_BME_in__MPU, I2C_short_timeout);
		Get_MPU6050_all_readings();
	}


	I2C_Select_bus(I2C_BUS_SEL_MPU__SI);
	Sensors.SI1145.Status = SI1145_Init(I2C_handle_BME_ex__SI, I2C_short_timeout);
	if (Sensors.SI1145.Status == HAL_OK)
	{
		Sensors.SI1145.Status = SI1145_read_ID(I2C_handle_BME_ex__SI, &Sensors.SI1145.ID, I2C_short_timeout);
		Get_SI1145_all_readings();
	}


  /*--------Max altitude read from stabilised data-------*/
	Get_BME280_ex_all_readings();
	Altitude_max = Sensors.BME280_External.Altitude;


  /*---------------UART receiver setup-------------------*/
	UART1_RxIsData = 0;
	UART1_RxBytes = 2;
	while(HAL_GPIO_ReadPin(GPIOA, GPIO_PIN_10) == 0);
	HAL_UART_Receive_IT(&huart1, UART1_RxBuf, 2);

	UART2_RxIsData = 0;
	UART2_RxBytes = 2;
	while(HAL_GPIO_ReadPin(GPIOA, GPIO_PIN_3) == 0);
	HAL_UART_Receive_IT(&huart2, UART2_RxBuf, 2);

	UART1_TxBuf[0] = 0x00;
	UART1_TxBuf[1] = Get_System_Status();
	HAL_UART_Transmit_IT(&huart1, UART1_TxBuf, 2);


  /*------------------Start timers-----------------------*/
	HAL_TIM_Base_Start_IT(&htim3);	// Sensor read cycle timer
	HAL_TIM_Base_Start_IT(&htim4);	// Flashes LEDs

	HAL_TIM_Base_Start_IT(&htim5);	// CAM1 heartbeat timer
	HAL_TIM_Base_Start_IT(&htim9);	// CAM2 heartbeat timer


  /*----------------- Camera init ----------------------*/
	CAM_1.OK_PIN = CAM1_OK_Pin;
	CAM_1.OK_PORT = CAM1_OK_GPIO_Port;
	CAM_1.ON_PIN = CAM1_ON_Pin;
	CAM_1.ON_PORT = CAM1_ON_GPIO_Port;
	CAM_1.START_PIN = CAM1_START_Pin;
	CAM_1.START_PORT = CAM1_START_GPIO_Port;
	CAM_1.REC_STATUS = CAM_NREC;
	CAM_1.TIM = &htim5;
	CAM_1.Do_Restart = 0;
	CAM_1.Do_EXTI = 0;
	CAM_1.Startup_delay = CAM_STARTUP_TIME;

	CAM_2.OK_PIN = CAM2_OK_Pin;
	CAM_2.OK_PORT = CAM2_OK_GPIO_Port;
	CAM_2.ON_PIN = CAM2_ON_Pin;
	CAM_2.ON_PORT = CAM2_ON_GPIO_Port;
	CAM_2.START_PIN = CAM2_START_Pin;
	CAM_2.START_PORT = CAM2_START_GPIO_Port;
	CAM_2.REC_STATUS = CAM_NREC;
	CAM_2.TIM = &htim9;
	CAM_2.Do_Restart = 0;
	CAM_2.Do_EXTI = 0;
	CAM_2.Startup_delay = CAM_STARTUP_TIME;

	CAM_ON(&CAM_1);
	CAM_ON(&CAM_2);
	CAM_START(&CAM_1);
	CAM_START(&CAM_2);


  /* USER CODE END 2 */

  /* Infinite loop */
  /* USER CODE BEGIN WHILE */
  while (1)
  {
	  if(UART1_RxIsData == 0)
		  UART1_RxBytes = 2;
	  if(UART2_RxIsData == 0)
		  UART2_RxBytes = 2;
    /* USER CODE END WHILE */

    /* USER CODE BEGIN 3 */
  }
  /* USER CODE END 3 */
}

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
/* USER CODE BEGIN 4 */
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

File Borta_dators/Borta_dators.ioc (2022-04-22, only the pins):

Mcu.UserName=STM32F401CEUx
PA1.GPIO_Label=ROPE_CUT_EN
PA1.Signal=GPIO_Output
PA10.Signal=USART1_RX
PA11.GPIO_Label=BUS_SEL_1
PA11.Signal=GPIO_Output
PA12.GPIO_Label=BUS_SEL_2
PA12.Signal=GPIO_Output
PA13.Signal=SYS_JTMS-SWDIO
PA14.Signal=SYS_JTCK-SWCLK
PA15.GPIO_Label=BUZZER
PA15.Signal=GPIO_Output
PA2.Signal=USART2_TX
PA3.Signal=USART2_RX
PA4.GPIO_Label=SD_CS
PA4.Signal=GPIO_Output
PA5.Signal=SPI1_SCK
PA6.Signal=SPI1_MISO
PA7.Signal=SPI1_MOSI
PA8.GPIO_Label=USER_LED1
PA8.Signal=GPIO_Output
PA9.Signal=USART1_TX
PB1.GPIO_Label=CAM2_OK
PB1.Signal=GPIO_Output
PB10.Signal=I2C2_SCL
PB12.GPIO_Label=USER_LED3
PB12.Signal=GPIO_Output
PB13.GPIO_Label=USER_LED5
PB13.Signal=GPIO_Output
PB14.GPIO_Label=USER_LED2
PB14.Signal=GPIO_Output
PB15.GPIO_Label=USER_LED4
PB15.Signal=GPIO_Output
PB2.GPIO_Label=CAM1_OK
PB2.Signal=GPIO_Output
PB3.Signal=I2C2_SDA
PB4.GPIO_Label=CAM2_START
PB4.Signal=GPXTI4
PB5.GPIO_Label=CAM1_START
PB5.Signal=GPXTI5
PB6.Signal=I2C1_SCL
PB7.Signal=I2C1_SDA
PB8.GPIO_Label=CAM2_ON
PB8.Signal=GPIO_Output
PB9.GPIO_Label=CAM1_ON
PB9.Signal=GPIO_Output

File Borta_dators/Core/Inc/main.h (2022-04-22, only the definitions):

#define ROPE_CUT_EN_Pin GPIO_PIN_1
#define ROPE_CUT_EN_GPIO_Port GPIOA
#define SD_CS_Pin GPIO_PIN_4
#define SD_CS_GPIO_Port GPIOA
#define CAM2_OK_Pin GPIO_PIN_1
#define CAM2_OK_GPIO_Port GPIOB
#define CAM1_OK_Pin GPIO_PIN_2
#define CAM1_OK_GPIO_Port GPIOB
#define USER_LED3_Pin GPIO_PIN_12
#define USER_LED3_GPIO_Port GPIOB
#define USER_LED5_Pin GPIO_PIN_13
#define USER_LED5_GPIO_Port GPIOB
#define USER_LED2_Pin GPIO_PIN_14
#define USER_LED2_GPIO_Port GPIOB
#define USER_LED4_Pin GPIO_PIN_15
#define USER_LED4_GPIO_Port GPIOB
#define USER_LED1_Pin GPIO_PIN_8
#define USER_LED1_GPIO_Port GPIOA
#define BUS_SEL_1_Pin GPIO_PIN_11
#define BUS_SEL_1_GPIO_Port GPIOA
#define BUS_SEL_2_Pin GPIO_PIN_12
#define BUS_SEL_2_GPIO_Port GPIOA
#define BUZZER_Pin GPIO_PIN_15
#define BUZZER_GPIO_Port GPIOA
#define CAM2_START_Pin GPIO_PIN_4
#define CAM2_START_GPIO_Port GPIOB
#define CAM2_START_EXTI_IRQn EXTI4_IRQn
#define CAM1_START_Pin GPIO_PIN_5
#define CAM1_START_GPIO_Port GPIOB
#define CAM1_START_EXTI_IRQn EXTI9_5_IRQn
#define CAM2_ON_Pin GPIO_PIN_8
#define CAM2_ON_GPIO_Port GPIOB
#define CAM1_ON_Pin GPIO_PIN_9
#define CAM1_ON_GPIO_Port GPIOB

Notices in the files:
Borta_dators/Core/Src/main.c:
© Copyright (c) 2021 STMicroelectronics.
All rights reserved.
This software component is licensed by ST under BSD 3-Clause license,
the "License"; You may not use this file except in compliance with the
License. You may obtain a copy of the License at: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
